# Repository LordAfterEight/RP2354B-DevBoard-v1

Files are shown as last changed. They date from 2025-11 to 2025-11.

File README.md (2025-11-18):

# RP2354B-DevBoard-v1
Repository for my first RP2354 based dev board

<p float="middle">
  
  
</p>

This dev board comes without external flash and only uses the 2MB of flash that come with the RP2354B chip, thus making this board only compatible with this specific version of the chip.

# Pinout
The two rows of pin headers are simply GPIO 0 - 19 on one side and GPIO 20 - 39 on the other. This means that the ADC pins of the RP2354B can **not** be used on this board as they're simply unconnected.

VBUS is directly connected to the micro-usb connector. 3V3/VSYS is connected to the output of the voltage regulator.

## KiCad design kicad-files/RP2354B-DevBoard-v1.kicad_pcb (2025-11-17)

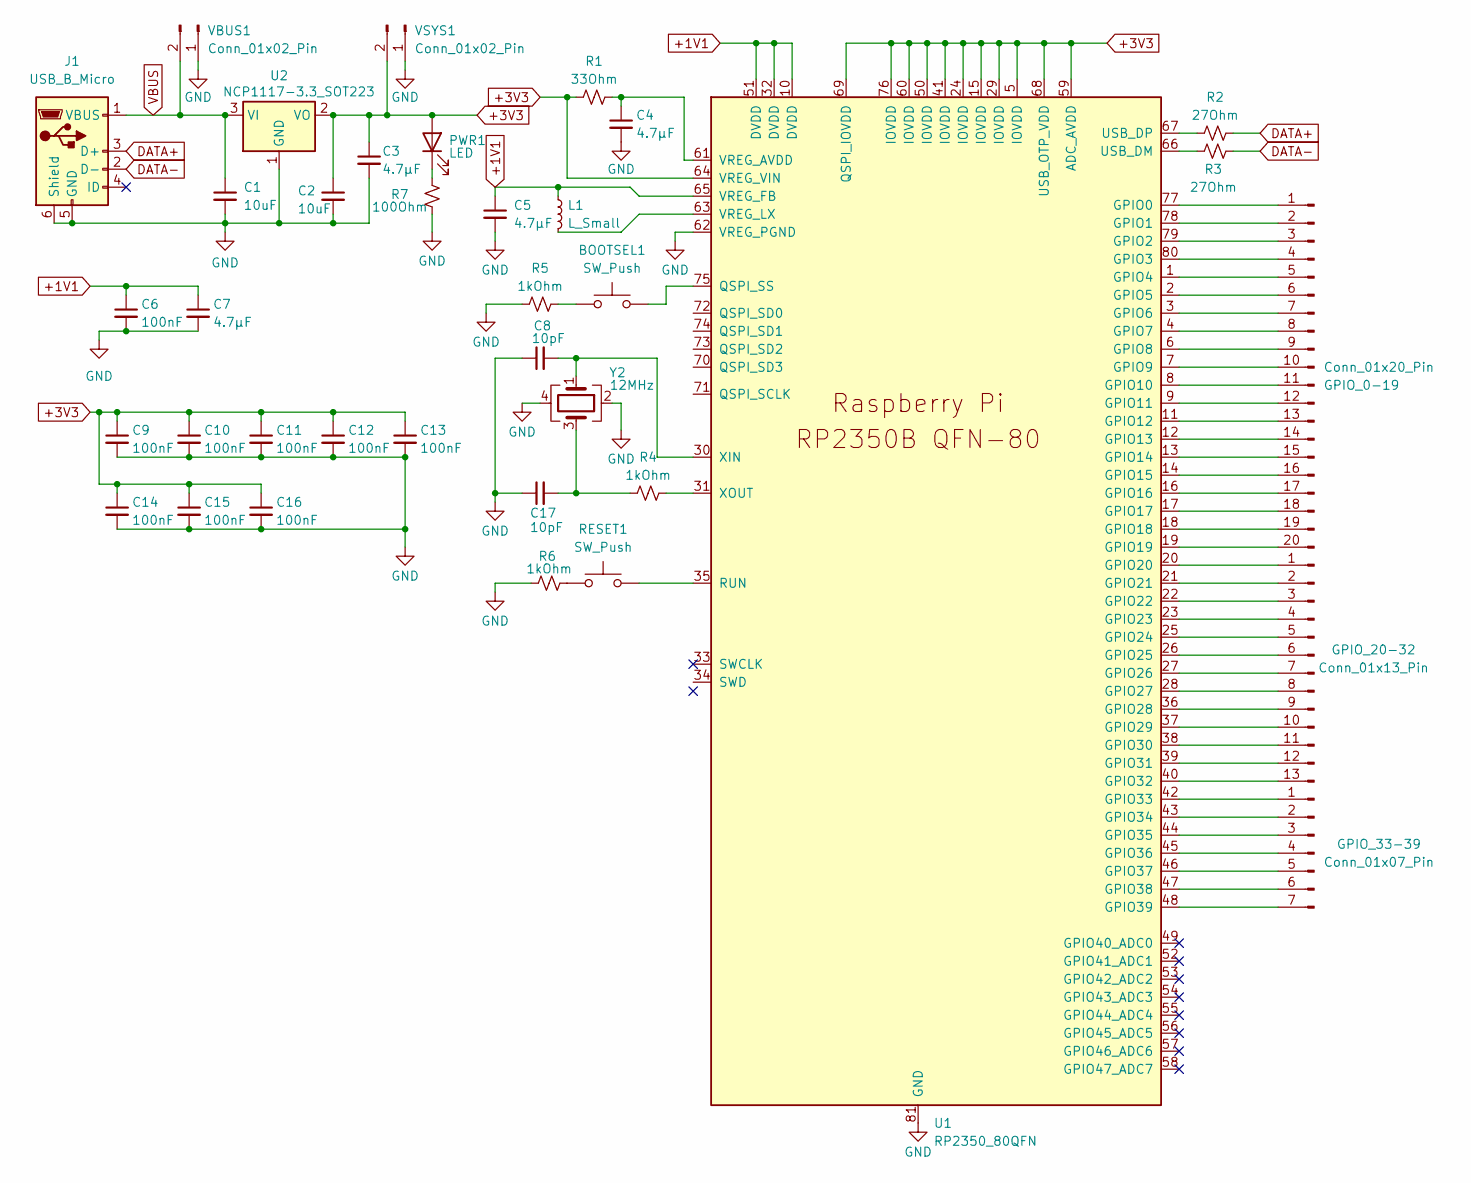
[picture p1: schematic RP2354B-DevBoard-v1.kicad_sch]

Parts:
BOOTSEL1: SW_Push; SW_PUSH_6mm
C1, C2: 10uF; C_0402_1005Metric_Pad0.74x0.62mm_HandSolder
C3, C4, C5, C7: 4.7µF; C_0402_1005Metric_Pad0.74x0.62mm_HandSolder
C6, C9, C10, C11, C12, C13, C14, C15, C16: 100nF; C_0402_1005Metric_Pad0.74x0.62mm_HandSolder
C8, C17: 10pF; C_0402_1005Metric_Pad0.74x0.62mm_HandSolder
GPIO_0-19: Conn_01x20_Pin; PinHeader_1x20_P2.54mm_Vertical
GPIO_20-32: Conn_01x13_Pin; PinHeader_1x13_P2.54mm_Vertical
GPIO_33-39: Conn_01x07_Pin; PinHeader_1x07_P2.54mm_Vertical
J1: USB_B_Micro; USB_Micro-B_Amphenol_10103594-0001LF_Horizontal
L1: L_Small; L_Coilcraft_0805HQ_2012Metric
PWR1: LED; LED_0603_1608Metric
R1: 33Ohm; R_0402_1005Metric_Pad0.72x0.64mm_HandSolder
R2, R3: 27Ohm; R_0402_1005Metric_Pad0.72x0.64mm_HandSolder
R4, R5, R6: 1kOhm; R_0402_1005Metric_Pad0.72x0.64mm_HandSolder
R7: 100Ohm; R_0402_1005Metric_Pad0.72x0.64mm_HandSolder
RESET1: SW_Push; SW_PUSH_6mm
U1: RP2350_80QFN; QFN-80-1EP_10x10mm_P0.4mm_EP3.4x3.4mm_ThermalVias
U2: NCP1117-3.3_SOT223; SOT-223-3_TabPin2
VBUS1: Conn_01x02_Pin; PinHeader_1x02_P2.54mm_Vertical
VSYS1: Conn_01x02_Pin; PinHeader_1x02_P2.54mm_Vertical
Y2: 12MHz; Crystal_SMD_EuroQuartz_MJ-4Pin_5.0x3.2mm_HandSoldering

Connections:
+1V1: C5.1, C6.1, C7.1, L1.1, U1.10 (DVDD), U1.32 (DVDD), U1.51 (DVDD), U1.65 (VREG_FB)
+3V3: C2.1, C3.1, C9.1, C10.1, C11.1, C12.1, C13.1, C14.1, C15.1, C16.1, PWR1.2 (A), R1.1, U1.5 (IOVDD), U1.15 (IOVDD), U1.24 (IOVDD), U1.29 (IOVDD), U1.41 (IOVDD), U1.50 (IOVDD), U1.59 (ADC_AVDD), U1.60 (IOVDD), U1.64 (VREG_VIN), U1.68 (USB_OTP_VDD), U1.69 (QSPI_IOVDD), U1.76 (IOVDD), U2.2 (VO), VSYS1.2; also elsewhere on the board
DATA+: J1.3 (D+), R2.2
DATA-: J1.2 (D-), R3.2
GND: C1.2, C2.2, C3.2, C4.2, C5.2, C6.2, C7.2, C8.1, C9.2, C10.2, C11.2, C12.2, C13.2, C14.2, C15.2, C16.2, C17.1, J1.5 (GND), J1.6 (Shield), R5.1, R6.1, R7.1, U1.62 (VREG_PGND), U1.81 (GND), U2.1 (GND), VBUS1.1, VSYS1.1, Y2.2, Y2.4
unnamed 5: BOOTSEL1.1, R5.2; also elsewhere on the board
unnamed: C17.2, R4.1, Y2.3
unnamed: GPIO_0-19.1, U1.77 (GPIO0)
unnamed: GPIO_0-19.2, U1.78 (GPIO1)
unnamed: GPIO_0-19.3, U1.79 (GPIO2)
unnamed: GPIO_0-19.4, U1.80 (GPIO3)
unnamed: GPIO_0-19.5, U1.1 (GPIO4)
unnamed: GPIO_0-19.6, U1.2 (GPIO5)
unnamed: GPIO_0-19.7, U1.3 (GPIO6)
unnamed: GPIO_0-19.8, U1.4 (GPIO7)
unnamed: GPIO_0-19.9, U1.6 (GPIO8)
unnamed: GPIO_0-19.10, U1.7 (GPIO9)
unnamed: GPIO_0-19.11, U1.8 (GPIO10)
unnamed: GPIO_0-19.12, U1.9 (GPIO11)
unnamed: GPIO_0-19.13, U1.11 (GPIO12)
unnamed: GPIO_0-19.14, U1.12 (GPIO13)
unnamed: GPIO_0-19.15, U1.13 (GPIO14)
unnamed: GPIO_0-19.16, U1.14 (GPIO15)
unnamed: GPIO_0-19.17, U1.16 (GPIO16)
unnamed: GPIO_0-19.18, U1.17 (GPIO17)
unnamed: GPIO_0-19.19, U1.18 (GPIO18)
unnamed: GPIO_0-19.20, U1.19 (GPIO19)
unnamed: GPIO_20-32.1, U1.20 (GPIO20)
unnamed: GPIO_20-32.2, U1.21 (GPIO21)
unnamed: GPIO_20-32.3, U1.22 (GPIO22)
unnamed: GPIO_20-32.4, U1.23 (GPIO23)
unnamed: GPIO_20-32.5, U1.25 (GPIO24)
unnamed: GPIO_20-32.6, U1.26 (GPIO25)
unnamed: GPIO_20-32.7, U1.27 (GPIO26)
unnamed: GPIO_20-32.8, U1.28 (GPIO27)
unnamed: GPIO_20-32.9, U1.36 (GPIO28)
unnamed: GPIO_20-32.10, U1.37 (GPIO29)
unnamed: GPIO_20-32.11, U1.38 (GPIO30)
unnamed: GPIO_20-32.12, U1.39 (GPIO31)
unnamed: GPIO_20-32.13, U1.40 (GPIO32)
unnamed: GPIO_33-39.1, U1.42 (GPIO33)
unnamed: GPIO_33-39.2, U1.43 (GPIO34)
unnamed: GPIO_33-39.3, U1.44 (GPIO35)
unnamed: GPIO_33-39.4, U1.45 (GPIO36)
unnamed: GPIO_33-39.5, U1.46 (GPIO37)
unnamed: GPIO_33-39.6, U1.47 (GPIO38)
unnamed: GPIO_33-39.7, U1.48 (GPIO39)
unnamed 47: PWR1.1 (K), R7.2; also elsewhere on the board
unnamed 48: R6.2, RESET1.1; also elsewhere on the board
unnamed 49: BOOTSEL1.2, U1.75 (QSPI_SS); also elsewhere on the board
unnamed 50: RESET1.2, U1.35 (RUN); also elsewhere on the board
unnamed: R3.1, U1.66 (USB_DM)
unnamed: R2.1, U1.67 (USB_DP)
unnamed: C4.1, R1.2, U1.61 (VREG_AVDD)
unnamed: L1.2, U1.63 (VREG_LX)
unnamed: C8.2, U1.30 (XIN), Y2.1
unnamed: R4.2, U1.31 (XOUT)
VBUS: C1.1, J1.1 (VBUS), U2.3 (VI), VBUS1.2

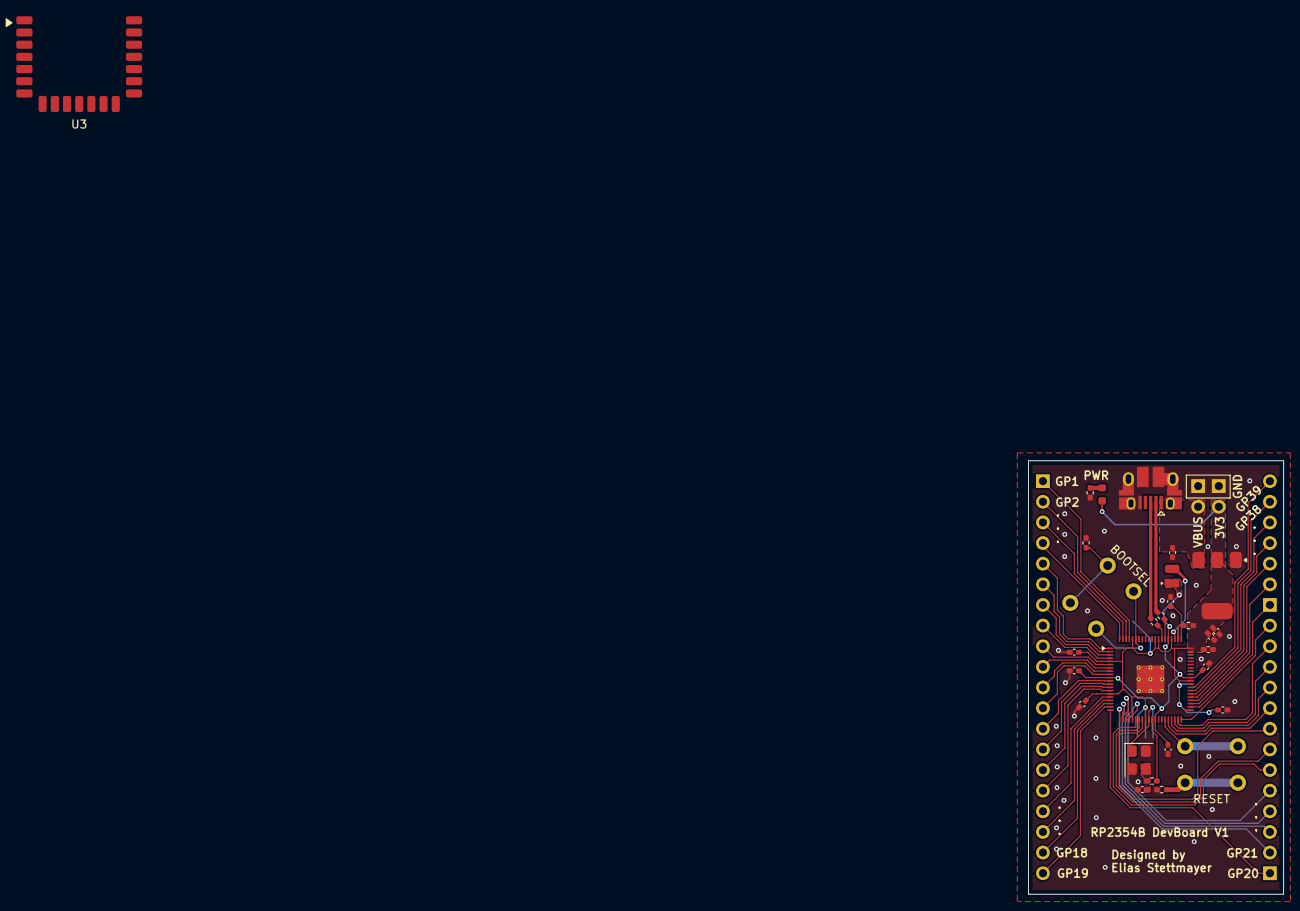
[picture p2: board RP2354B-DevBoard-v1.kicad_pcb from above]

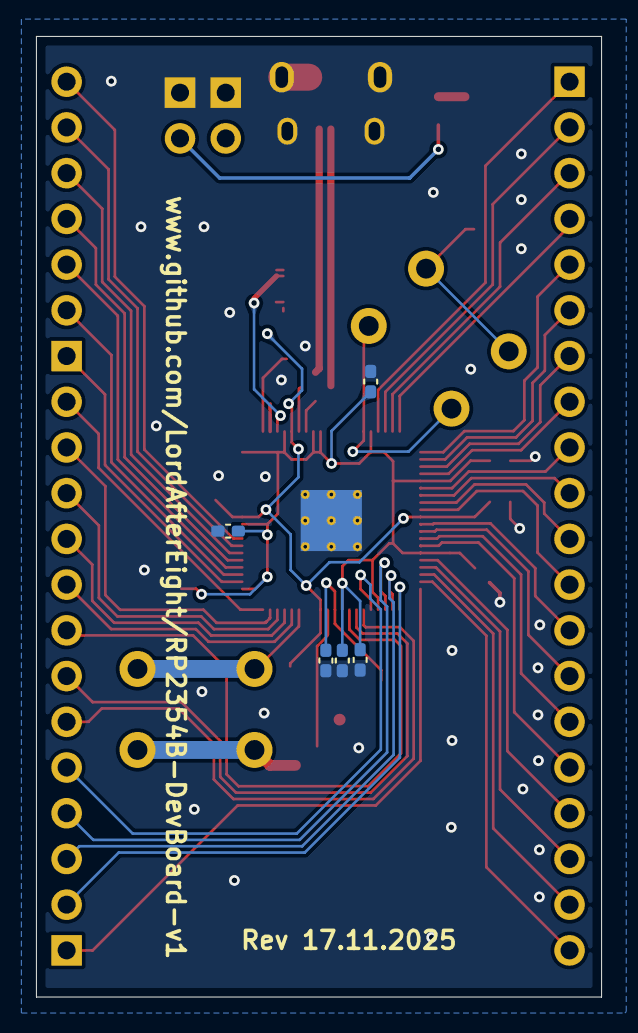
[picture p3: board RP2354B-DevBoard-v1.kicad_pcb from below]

Board: 2 copper layers, 31.4 x 53.4 mm, 38 parts (8 on the bottom side), 58 nets.

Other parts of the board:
BOOTSEL: SW_Push; SW_PUSH_6mm_H8mm
PWR: LED; LED_0603_1608Metric
RESET: SW_Push; SW_PUSH_6mm_H8mm
U3: <value>; RMC20452T

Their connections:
+3V3: PWR.2 (A); also elsewhere on the board
unnamed 5: BOOTSEL.1; also elsewhere on the board
unnamed 47: PWR.1 (K); also elsewhere on the board
unnamed 48: RESET.1; also elsewhere on the board
unnamed 49: BOOTSEL.2; also elsewhere on the board
unnamed 50: RESET.2; also elsewhere on the board

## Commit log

2025-11-15 Add KiCad files
    [RP2354B-DevBoard-v1.kicad_pcb, RP2354B-DevBoard-v1.kicad_sch]
2025-11-15 Create KiCad subfolder
    [RP2354B-DevBoard-v1.kicad_pcb, RP2354B-DevBoard-v1.kicad_sch]
2025-11-17 Update KiCad files to new board revision
    [RP2354B-DevBoard-v1.kicad_pcb]
2025-11-17 Move updated files to their subfolder
    [RP2354B-DevBoard-v1.kicad_pcb]
